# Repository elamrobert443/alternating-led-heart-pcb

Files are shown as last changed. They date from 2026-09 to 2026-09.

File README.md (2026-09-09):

# Alternating LED Heart PCB

A custom heart-shaped PCB designed as a Mother's Day gift.

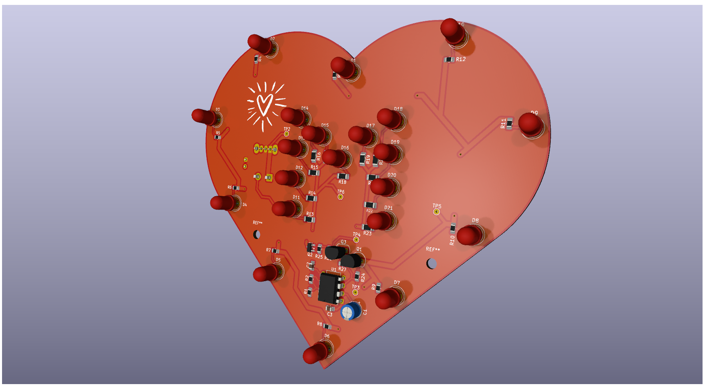
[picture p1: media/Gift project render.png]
3D PCB Render


## Features

- Heart-shaped PCB
- Red LED bank forming an "M"
- White perimeter LED bank
- Alternating blinking effect (see video in the "media" folder)
- 555 timer oscillator
- BJT inverter for complementary signals
- MOSFET and BJT LED switching circuits
- 4xAAA battery power supply
- Custom 3D-printed stand

## Overview of Design Decisions
The circuit uses a 555 timer to generate a square wave in its astable oscillator configuration. A design requirement was to have the different colored LED banks to turn on when the other is off (e.g. if the white LEDs are on, turn the red ones off, and vice versa). I opted to implement this behavior with transistors, as doing so with a microcontroller would've been overkill. A BJT inverter creates the complementary signal needed for the two LED banks to blink in an alternating fashion, with the complemented signal tied to the base of the driving transistor of one bank, and the direct 555 timer output tied to the base of the other bank's transistor. Why do transistors control the LED banks? One goal of the design was to maximize each LED's brightness to ensure visibility during daytime. With the amount of LEDs wired in parallel on each bank, transistors were necessary to handle each bank's loads in order to avoid approaching or exceeding the 555 timer's maximum rated output current. However, in the media/heart-pcb-video.mp4 file, it appears both banks are on at the same time. I suspect this is possibly due to the white LED bank utilizing a BJT, which command slower switching speeds compared to MOSFETs (which is what the red LEDs use), but without an oscilloscope I can't verify that with certainty, as I haven't ruled out camera trickery. Why are the transistors for each bank different? At some point I want to compare their behaviors on this specific board, which I haven't done beyond circuit simulation via KiCad.

In the event that debugging the board was required, multimeter test points were added to relevant points in each net, but I never ended up needing to use them beyond checking continuity before plugging in the batteries. Including the test points, most components chosen for this board ended up being through-hole in order to give myself more soldering experience without needing a ton of additional equipment. However, I opted for surface mount technology for parts such as resistors or ceramic capacitors as I didn't have much (or any) of either in my electronics inventory.

The PCB was designed in KiCad and manufactured through JLCPCB. Component selection included evaluating part substitutions when ordering from JLCPCB to reduce cost while maintaining functionality (a BOM can be found on this repository). The custom plastic stand for this board was designed with Autodesk Fusion and printed with a Bambu P1P using standard PLA. To prevent the assembled gift from tipping over, the stand was designed so that the weight of the board's batteries minimized the height of the gift's center of gravity. 

This is my first PCB, and was made at the tail end of my freshman year at college (thus before I took any Electrical Engineering classes). Feel free to leave comments or critiques at this email (rfe295@tamu.edu).

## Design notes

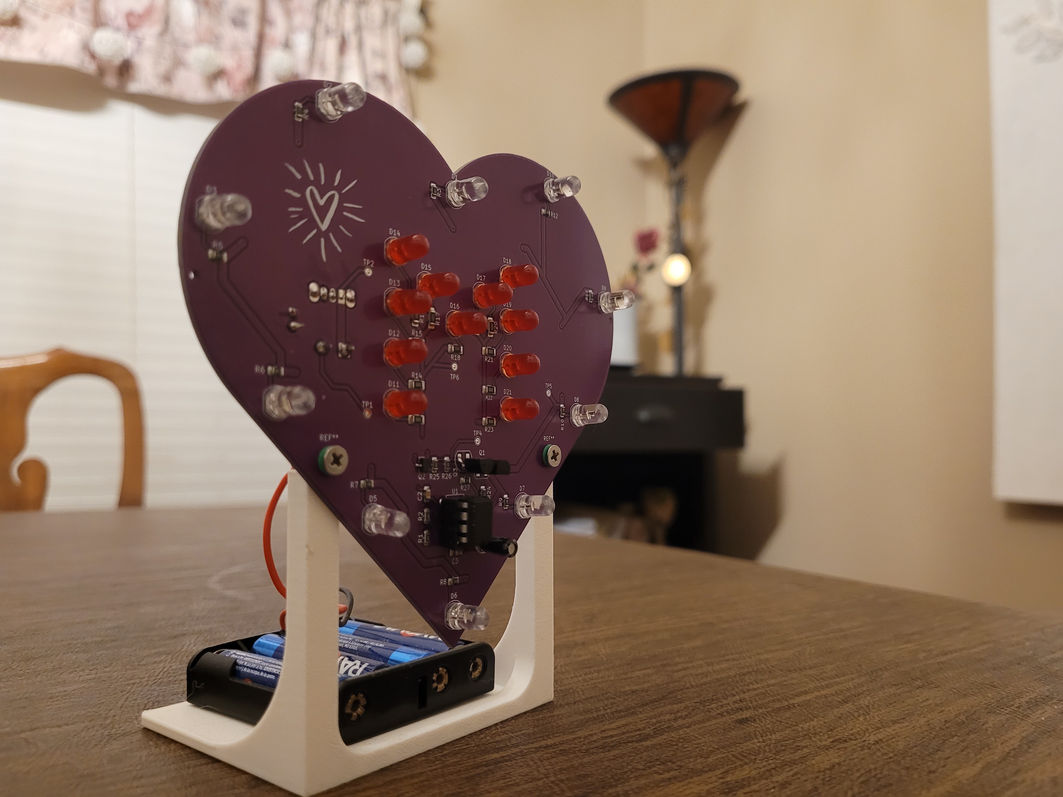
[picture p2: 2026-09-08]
media/heart-pcb-off.jpg

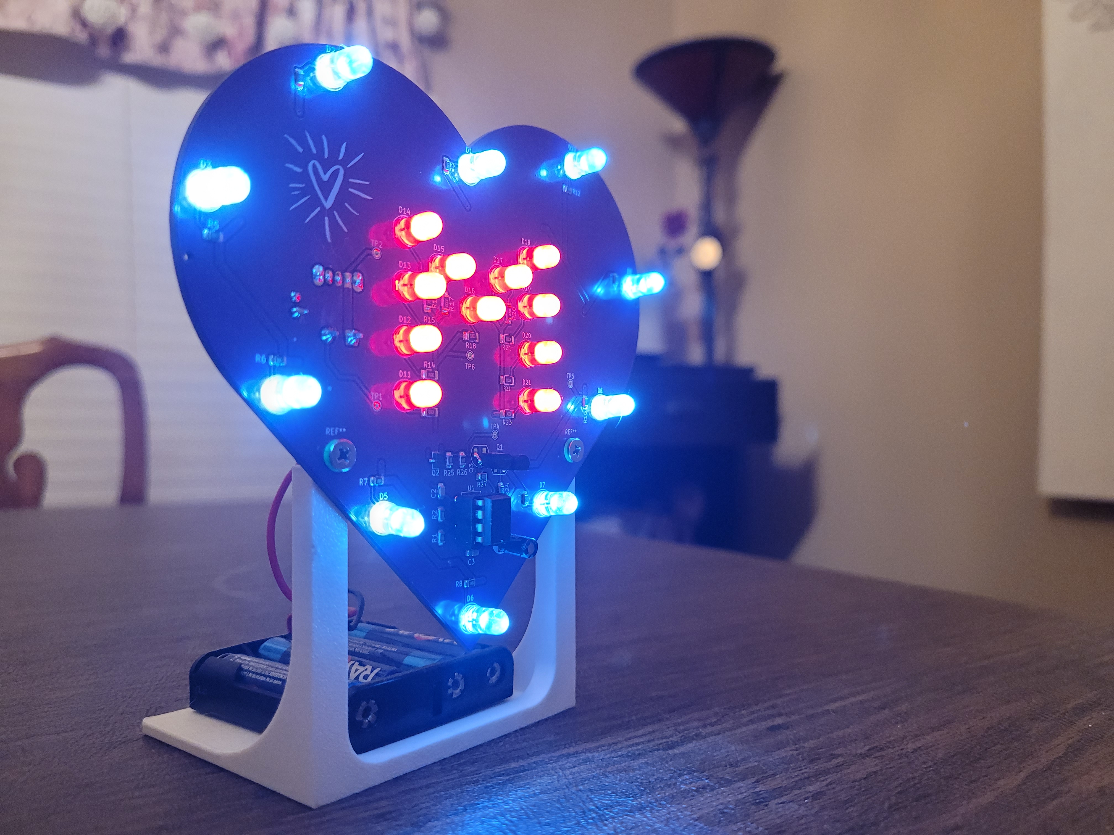
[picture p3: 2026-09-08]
media/heart-pcb-on.jpg

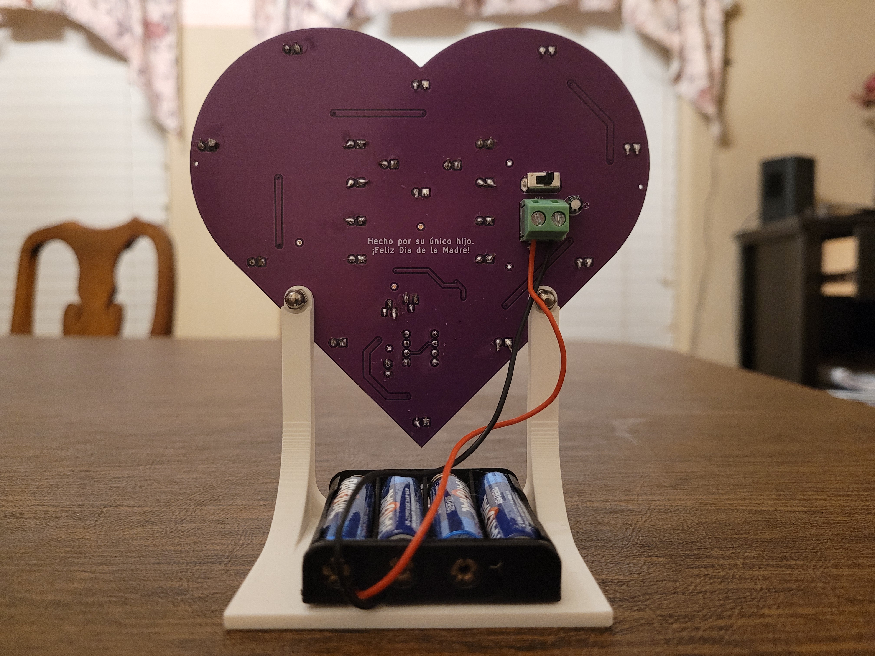
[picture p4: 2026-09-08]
media/heart-pcb-back.jpg

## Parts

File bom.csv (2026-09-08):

Designator | Footprint | Quantity | Value | LCSC Part #
BT1 | TerminalBlock_Phoenix_MKDS-1,5-2-5.08_1x02_P5.08mm_Horizontal | 1 | Terminal Block, 2-pin, 5.08mm pitch | C709041
C1, C4 | CP_Radial_D5.0mm_P2.50mm | 2 | 10uF | C2029
C2 | 805 | 1 | 10nF | C1710
C3 | 805 | 1 | 0.1uF | C126469
D1, D2, D3, D4, D5, D6, D7, D8, D9, D10 | LED_D5.0mm | 10 | WHITE LED 5mm | C74067
D11, D12, D13, D14, D15, D16, D17, D18, D19, D20, D21 | LED_D5.0mm | 11 | RED LED 5mm | C87271
Q1 | TO-92L_HandSolder | 1 | PN2222A | C118536
Q2 | SOT-23 | 1 | AO3400A | C20917
Q3 | TO-92_HandSolder | 1 | PN2222A | C118536
R1, R26 | 805 | 2 | 10K | C17414
R3, R4, R5, R6, R7, R8, R9, R10, R11, R12 | 805 | 10 | 330 | C17630
R13, R14, R15, R16, R17, R18, R19, R20, R21, R22, R23 | 1206 | 11 | 270 | C17887
R2 | 805 | 1 | 70K | C17801
R24 | 805 | 1 | 360 | C17630
R25 | 805 | 1 | 100 | C17408
R27 | 805 | 1 | 2.2K | C17520
SW1 | SW_Slide_SPDT_Straight_CK_OS102011MS2Q | 1 | SW_SPST | C221829
TP1, TP2, TP3, TP4, TP5, TP6 | TestPoint_THTPad_D1.5mm_Drill0.7mm | 6 | TestPoint_Probe
U1 | DIP-8_W7.62mm | 1 | IC Socket, DIP-8 | C305904
U1IC | DIP-8_W7.62mm | 0 | NE555P DNP
